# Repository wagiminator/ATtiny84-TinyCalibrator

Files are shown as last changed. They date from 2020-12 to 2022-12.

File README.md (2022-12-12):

# TinyCalibrator - OSC Calibrator and High-Voltage Fuse Resetter
Because the 8-pin ATtinys only have a few GPIO pins available, they are usually operated without an external clock. The internal oscillator does a good job in most applications, but when it comes to precise timing, its +/-10% accuracy is often insufficient. Fortunately, the oscillator can be calibrated, increasing its accuracy to +/-2% or better. There are a few ways to perform this manual calibration, but several steps are required. The TinyCalibrator does this fully automatically by a push of a button. In order to make the device more versatile, a high-voltage fuse resetter was also integrated, with which "bricked" ATtinys can be reset to the factory state. For an in-circuit oscillator calibrator take a look at [TinyICOC](https://github.com/wagiminator/ATtiny84-TinyICOC).

- Project Video (YouTube): https://youtu.be/PQvtNVte2JE
- Design Files (EasyEDA): https://easyeda.com/wagiminator/attiny84-tinycalibrator

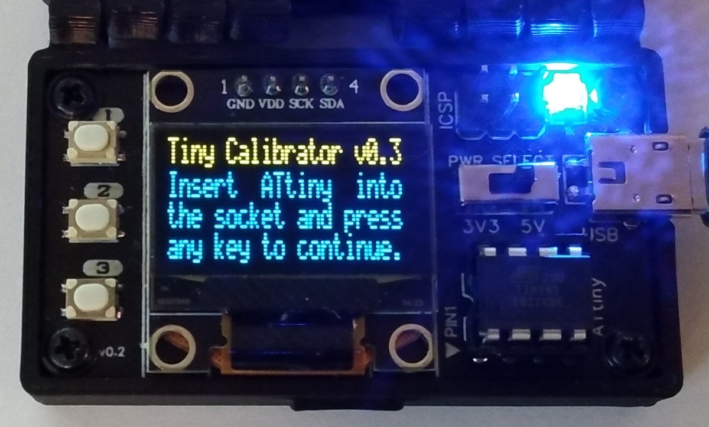
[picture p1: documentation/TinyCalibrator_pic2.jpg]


# Hardware
The TinyCalibrator is supplied with 5V via a [Micro USB connector](https://aliexpress.com/wholesale?SearchText=micro+usb+2pin+dip). Since the frequency of the oscillator depends on the supply voltage of the ATtiny, an [HT7333](https://datasheet.lcsc.com/szlcsc/Holtek-Semicon-HT7333-A_C21583.pdf) voltage regulator was integrated. A switch can then be used to choose whether the oscillator should be calibrated for 3.3V or 5V.

The [ATtiny84](http://ww1.microchip.com/downloads/en/devicedoc/Atmel-7701_Automotive-Microcontrollers-ATtiny24-44-84_Datasheet.pdf) was chosen as the microcontroller for the TinyCalibrator because it has exactly the necessary number of GPIO pins. For accurate frequency measurements, the ATtiny84 is operated with an external 12 MHz crystal. Since the current software version only requires about 3.7 KByte, an ATtiny44 can also be used.

To generate the 12V for the High-Voltage Serial Programmer, an [ST662A](https://datasheet.lcsc.com/szlcsc/2004081608_STMicroelectronics-ST662ACD-TR_C500661.pdf) charge pump IC was chosen, which was specially designed for such applications and needs only a few external components. The 12V is controlled by a MOSFET and applied to the RESET pin of the target ATtiny if necessary. The remaining programming lines to the target are protected against a short circuit with resistors.

The user interface utilizes three buttons and a [128x64 pixels OLED display](http://aliexpress.com/wholesale?SearchText=128+64+0.96+oled+new+4pin).

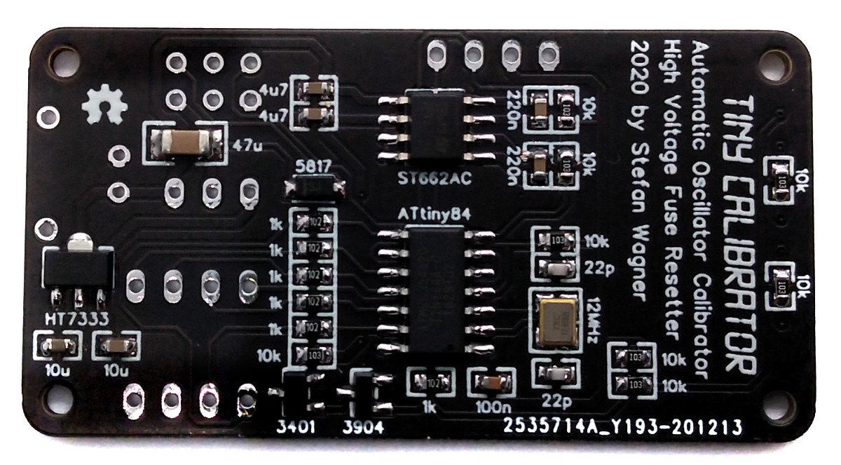
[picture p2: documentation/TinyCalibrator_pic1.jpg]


# Software
## Basic Principle
To carry out the calibration, a program is first uploaded to the target ATtiny using the integrated High-Voltage Serial Programmer. In addition, the factory oscillator calibration value (OSCCAL) is written to the EEPROM. The program on the target ATtiny reads the EEPROM and writes the value to the OSCCAL register. Then it applies an oscillating signal with half the clock frequency to pin PB0. Since the fuses were previously set so that the target ATtiny runs with a prescaler of 8, a signal with 1/16 of the oscillator frequency is applied to PB0.

```c
#include <avr/io.h>
#include <avr/eeprom.h>

int main(void) {
  OSCCAL = eeprom_read_byte(0);
  DDRB   = 0b00000001;
  TCCR0A = 0b01000010;
  TCCR0B = 0b00000001;
  while(1);
}
```

This frequency is measured by the TinyCalibrator and compared with the target value. The oscillator calibration value (OSCCAL) is then adjusted accordingly and written to the EEPROM of the target ATtiny. This process is repeated until the OSCCAL value, which leads to the lowest frequency deviation, has been found.

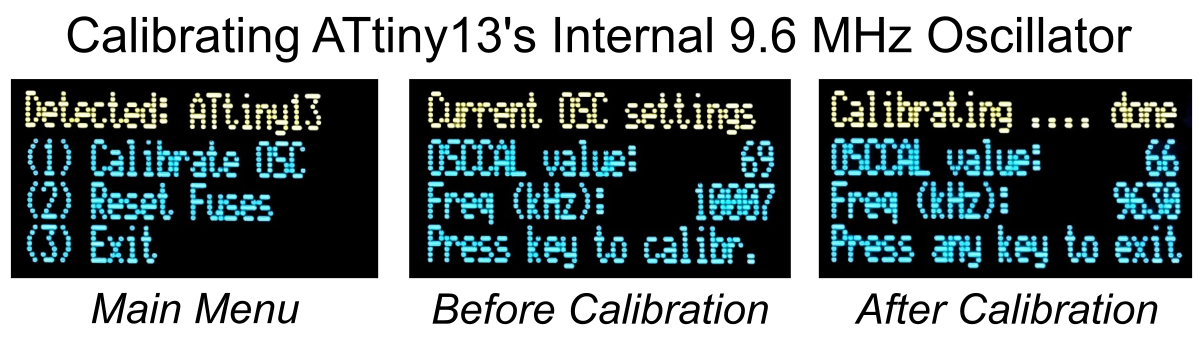
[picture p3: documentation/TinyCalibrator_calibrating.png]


## High-Voltage Serial Programmer
The code for the High-Voltage Serial Programmer (HVSP) is quite unspectacular. Simply put, for each action, a series of instructions are sent over the data lines to the target ATtiny and the corresponding response is read. The process and the instructions are well described in the data sheet.

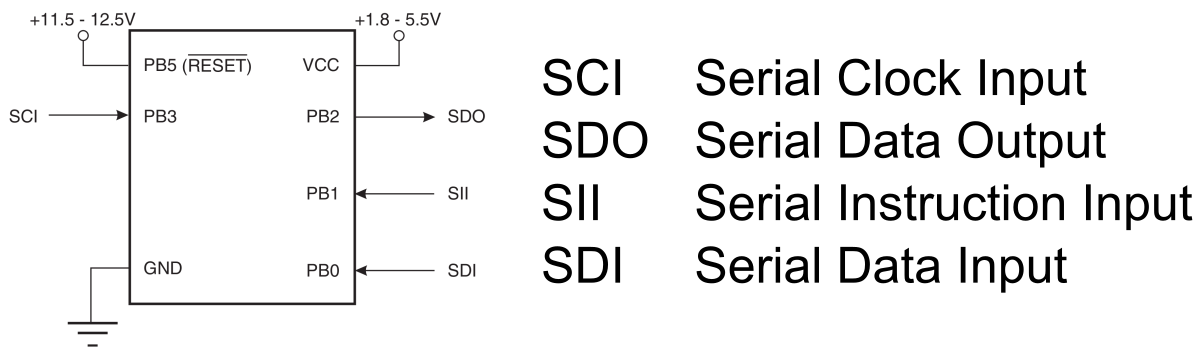
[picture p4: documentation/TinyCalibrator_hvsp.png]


## Frequency Measurement
The timer/counters of the ATtiny84 are used for the frequency measurement. PB0 of the target ATtiny, which outputs a signal with 1/16 of its oscillator frequency, is connected to the T0 input of the ATtiny84. Timer0 counts the pulses at T0 and timer1 stops the measurement after a time of 32 milliseconds. From this, the oscillator frequency of the target ATtiny can finally be calculated.

## I²C OLED Implementation
The I²C protocol implementation is based on a crude bitbanging method. It was specifically designed for the limited resources of ATtiny10 and ATtiny13, but it works with some other AVRs (including the ATtiny84) as well. The functions for the OLED are adapted to the SSD1306 OLED module, but they can easily be modified to be used for other modules. In order to save resources, only the basic functionalities which are needed for this application are implemented. For a detailed information on the working principle of the I²C OLED implementation visit [TinyOLEDdemo](https://github.com/wagiminator/attiny13-tinyoleddemo).

## Compiling and Uploading
### If using the Arduino IDE
- Make sure you have installed [ATtinyCore](https://github.com/SpenceKonde/ATTinyCore).
- Go to **Tools -> Board -> ATtinyCore** and select **ATtiny24/44/84(a) (No bootloader)**.
- Go to **Tools** and choose the following board options:
  - **Chip:**           ATtiny84(a)
  - **Clock:**          12 MHz (external)
  - **Millis/Micros:**  disabled
  - Leave the rest at the default settings
- Connect your programmer to your PC and to the ICSP header of the device.
- Go to **Tools -> Programmer** and select your ISP programmer (e.g. [USBasp](https://aliexpress.com/wholesale?SearchText=usbasp)).
- Go to **Tools -> Burn Bootloader** to burn the fuses.
- Open TinyCalibrator sketch and click **Upload**.

### If using the precompiled hex-file
- Make sure you have installed [avrdude](https://learn.adafruit.com/usbtinyisp/avrdude).
- Connect your programmer to your PC and to the ICSP header of the device.
- Open a terminal.
- Navigate to the folder with the hex-file.
- Execute the following command (if necessary replace "usbasp" with the programmer you use):
  ```
  avrdude -c usbasp -p t84 -U lfuse:w:0xff:m -U hfuse:w:0xd5:m -U efuse:w:0xff:m -U flash:w:tinycalibrator.hex
  ```

### If using the makefile (Linux/Mac)
- Make sure you have installed [avr-gcc toolchain and avrdude](http://maxembedded.com/2015/06/setting-up-avr-gcc-toolchain-on-linux-and-mac-os-x/).
- Connect your programmer to your PC and to the ICSP header of the device.
- Open a terminal.
- Navigate to the folder with the makefile and the Arduino sketch.
- Run `DEVICE=attiny84 PROGRMR=usbasp make install` to compile, burn the fuses and upload the firmware (change DEVICE and PROGRMR accordingly).

# Operating Instructions
1. Select the desired supply voltage (3.3V or 5V) with the switch.
2. Connect a 5V power supply to the micro USB port.
3. Place the ATtiny13/25/45/85 in the IC socket and press any key. Use an [SOP adapter](https://aliexpress.com/wholesale?SearchText=sop-8+150mil+200mil+adapter) for SMD parts.
4. Select the function you want and follow the instructions on the display.

After the calibration process, the optimal OSCCAL value remains in memory address 0 of the EEPROM and can continue to be used. To do this, program the EEFUSE to preserve EEPROM memory through the chip erase cycle, otherwise the OSCCAL value will be lost after uploading new firmware. Your code should then contain the following function:

```c
#include <avr/eeprom.h>
void readOSCCAL(void) {
  uint8_t value = eeprom_read_byte(0);
  if (value < 0xFF) OSCCAL = value;
}
```

Of course, the OSCCAL value can also be set directly without the EEPROM. Remember that the OSCCAL value is displayed in hexadecimal.

```c
OSCCAL = 0x66;
```

# References, Links and Notes
1. [TinyHVSP](https://github.com/wagiminator/ATtiny84-TinyHVSP)
2. [TinyICOC](https://github.com/wagiminator/ATtiny84-TinyICOC)
3. [I²C OLED Tutorial](https://github.com/wagiminator/attiny13-tinyoleddemo)
4. [Ralph Doncaster's PiggyFuse](https://nerdralph.blogspot.com/2018/05/piggyfuse-hvsp-avr-fuse-programmer.html)
5. [Oscillator Calibration Sketch for ATtiny13](https://github.com/MCUdude/MicroCore#internal-oscillator-calibration)
6. [Oscillator Calibration Sketch for ATtiny25/45/85](http://ernstc.dk/arduino/tinytuner.html)
7. [ATtiny84 Datasheet](http://ww1.microchip.com/downloads/en/devicedoc/Atmel-7701_Automotive-Microcontrollers-ATtiny24-44-84_Datasheet.pdf)
8. [ATtiny85 Datasheet](https://ww1.microchip.com/downloads/en/DeviceDoc/Atmel-2586-AVR-8-bit-Microcontroller-ATtiny25-ATtiny45-ATtiny85_Datasheet.pdf)
9. [ATtiny13A Datasheet](http://ww1.microchip.com/downloads/en/DeviceDoc/doc8126.pdf)

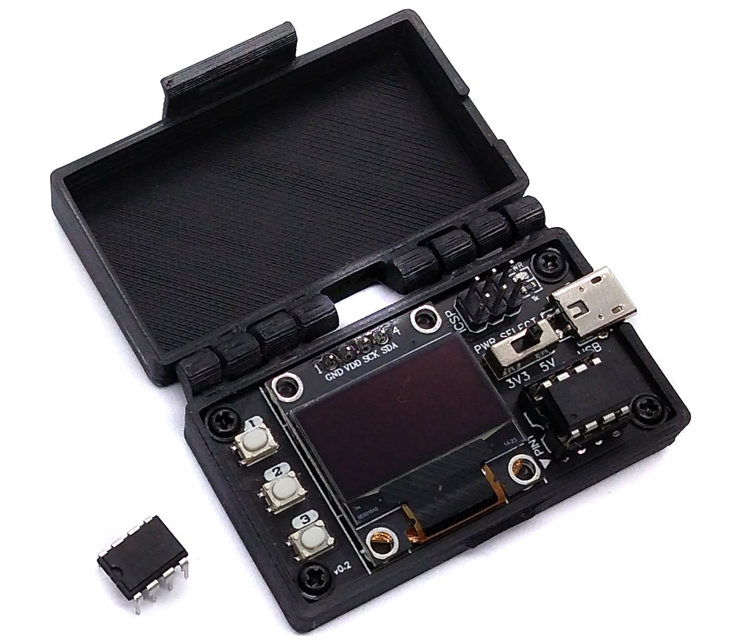
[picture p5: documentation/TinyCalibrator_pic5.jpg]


# License


This work is licensed under Creative Commons Attribution-ShareAlike 3.0 Unported License. 
(http://creativecommons.org/licenses/by-sa/3.0/)

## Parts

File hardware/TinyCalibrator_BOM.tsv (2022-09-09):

ID | Name | Designator | Footprint | Quantity | Manufacturer Part | Manufacturer | Supplier | Supplier Part | Price
1 | 100n | C1 | 603 | 1 | CC0603KRX7R9BB104 | YAGEO | LCSC | C14663 | 0.0041
2 | 47u | C2 | 1206 | 1 | 1206F476M160NT | FH | LCSC | C30300 | 0.3645
3 | 22p | C3,C4 | 603 | 2 | CL10C220JB8NNNC | SAMSUNG | LCSC | C1653 | 0.0054
4 | 220n | C5,C6 | 603 | 2 | CL10B224KA8NNNC | SAMSUNG | LCSC | C21120 | 0.0069
5 | 4u7 | C7,C8 | 603 | 2 | CL10A475KA8NQNC | SAMSUNG | LCSC | C69335 | 0.0273
6 | 10u | C9,C10 | 603 | 2 | CL10A106MA8NRNC | SAMSUNG | LCSC | C96446 | 0.0359
7 | 5817 | D1 | SCHOTTKY-SOD-123 | 1 | 1N5817W |  | LCSC | C727113 | 0.0286
8 | ICSP | H1 | ICSP-6-B | 1 | C65114 | BOOMELE | LCSC | C65114 | 0.0342
9 | OLED | H2 | I2C OLED 0.96 NEW | 1 | SSD1306 I2C OLED
10 | PWR | LED1 | LED_0603 | 1 | 19-217/BHC-ZL1M2RY/3T | EVERLIGHT | LCSC | C72041 | 0.0182
11 | AO3401A | Q1 | SOT-23-3 | 1 | AO3401A | AOS | LCSC | C15127 | 0.1864
12 | MMBT3904 | Q2 | SOT-23-3 | 1 | MMBT3904 | CJ | LCSC | C20526 | 0.0177
13 | 1k | R2,R5,R7,R8,R9,R10,R15 | 603 | 7 | 0603WAF1001T5E | UniOhm | LCSC | C21190 | 0.0013
14 | 10k | R1,R3,R4,R6,R11,R12,R13,R14 | 603 | 8 | 0603WAF1002T5E | UniOhm | LCSC | C25804 | 0.0014
15 | TS-1089S-02526 | SW1,SW2,SW3 | SW-SMD_4P-L4.2-W3.3 | 3 | TS-1089S-02526 | XUNPU | LCSC | C455282 | 0.0534
16 | PWRSLCT | SW4 | SLIDE SWITCH DPDT 1P2T | 1 | SS-12D01-G2 | USAKRO | LCSC | C698215 | 0.0454
17 | ATTINY84A-SSU | U1 | SOIC-14_150MIL | 1 | ATTINY84A-SSU | MICROCHIP | LCSC | C144333 | 2.0002
18 | ST662ACD-TR | U2 | SOP-8_150MIL | 1 | ST662ACD-TR | STMicroelectronics | LCSC | C500661 | 0.8368
19 | HT7333-A | U3 | SOT-89-3_L4.5-W2.5-P1.50-LS4.2-BR | 1 | HT7333-A | HOLTEK | LCSC | C21583 | 0.2939
20 | DIP8 SOCKET | U4 | DIP8 PACKAGE | 1 | DS1009-08AT1NX-0A2 | CONNFLY | LCSC | C72124 | 0.0336
21 | USB PWR Connector | USB1 | USB PWR CONNECTOR | 1 | KH-MICRO-SMT.J-2P | Shenzhen Kinghelm Elec | LCSC | C2688799 | 0.0549
22 | 12MHz | X1 | OSC-SMD_3225 | 1 | X322512MSB4SI | YXC | LCSC | C9002 | 0.1064

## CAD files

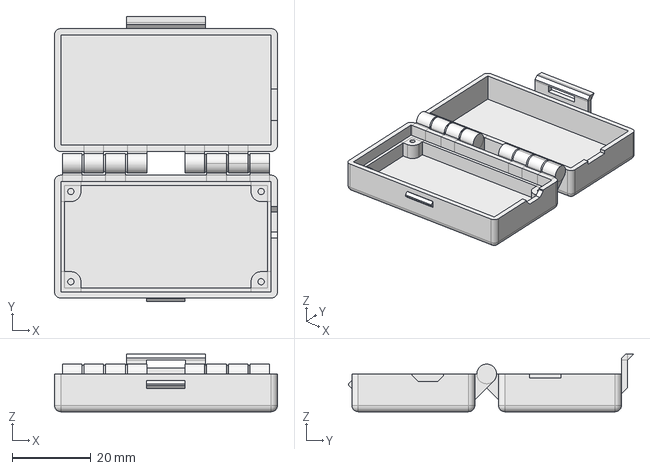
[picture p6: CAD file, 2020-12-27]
3dprint/TinyCalibrator_case.fcstd
56.6 x 72.4 x 14.6 mm

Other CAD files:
3dprint/TinyCalibrator_case.stl

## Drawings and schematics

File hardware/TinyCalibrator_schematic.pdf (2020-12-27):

## ATtiny84 Microcontroller

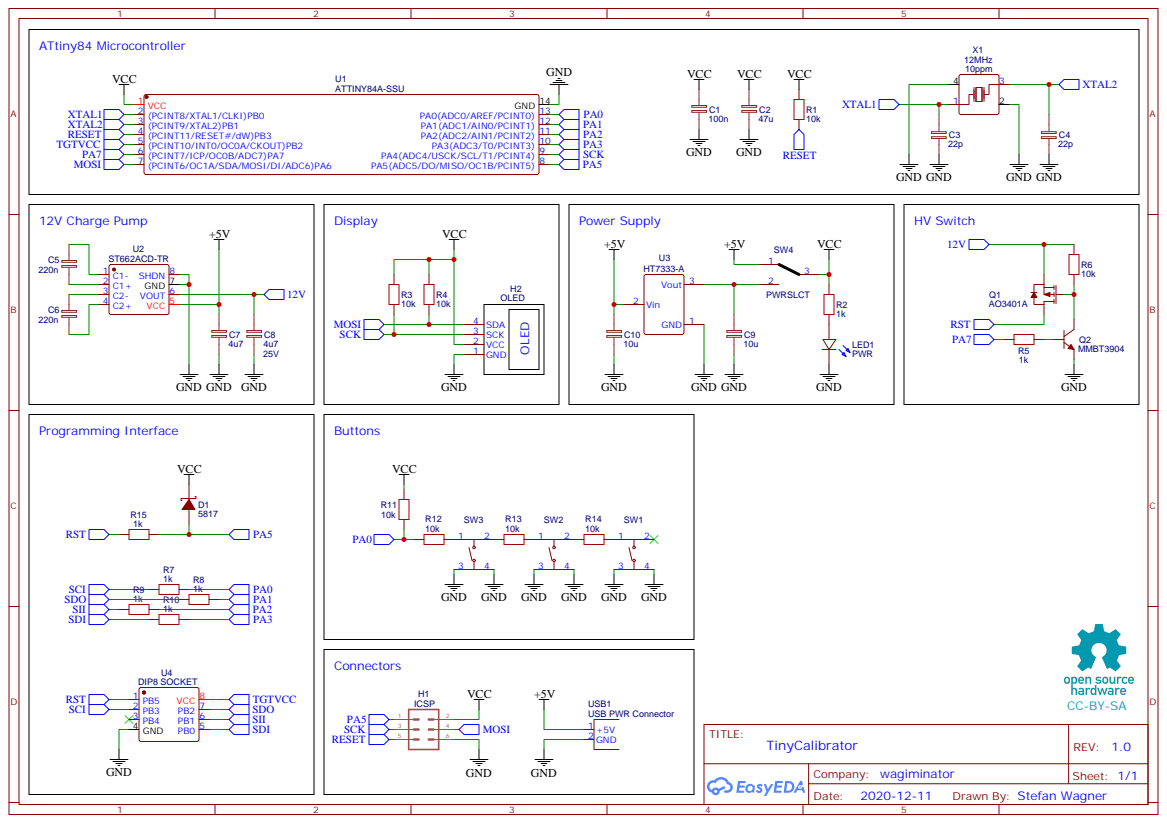
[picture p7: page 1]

GND GND GND

Drawn By: Stefan Wagner

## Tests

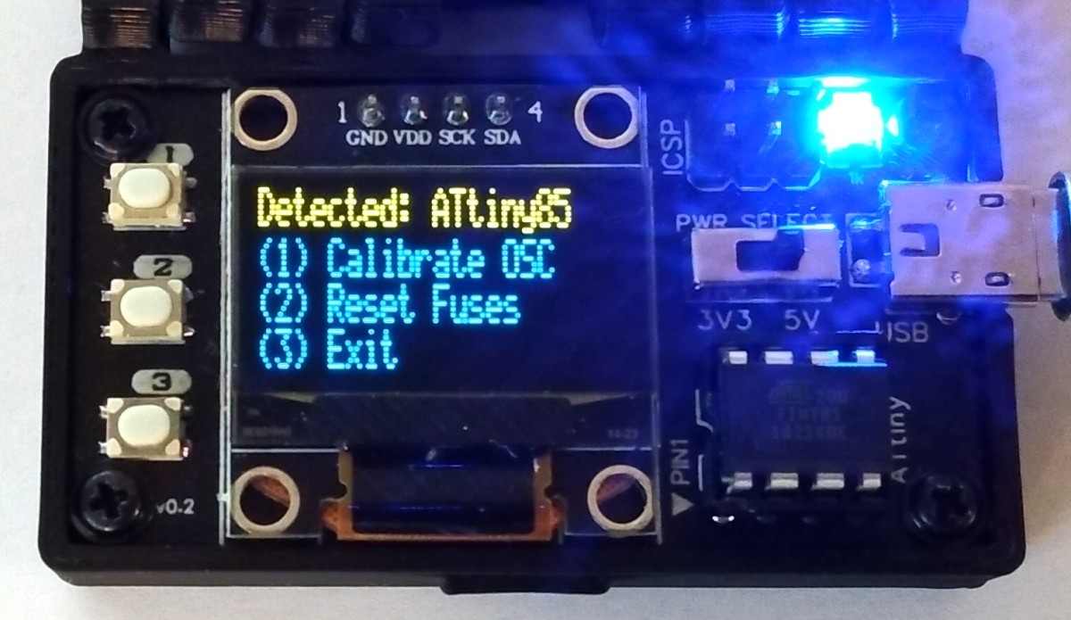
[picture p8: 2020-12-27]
documentation/TinyCalibrator_pic3.jpg

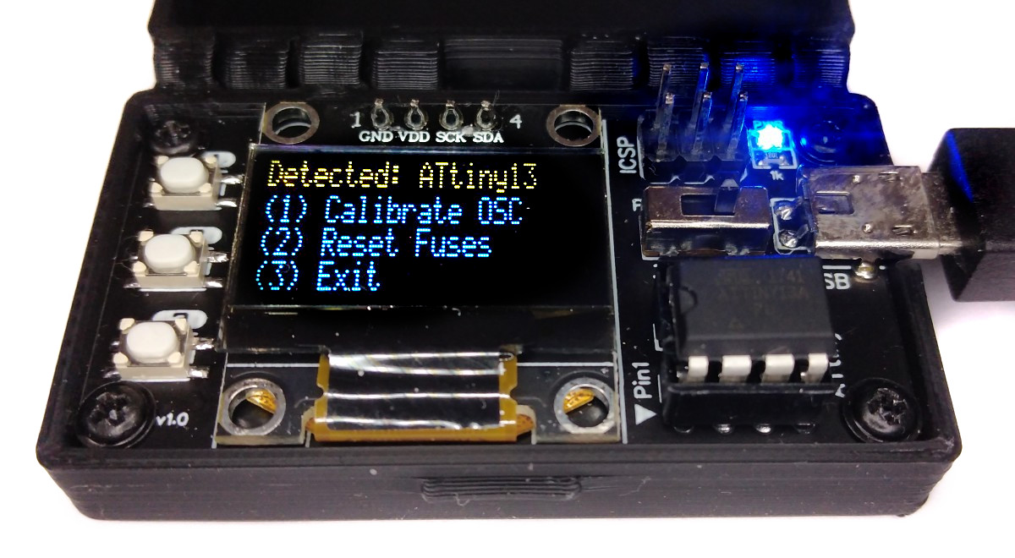
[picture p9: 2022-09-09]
documentation/TinyCalibrator_pic6.jpg

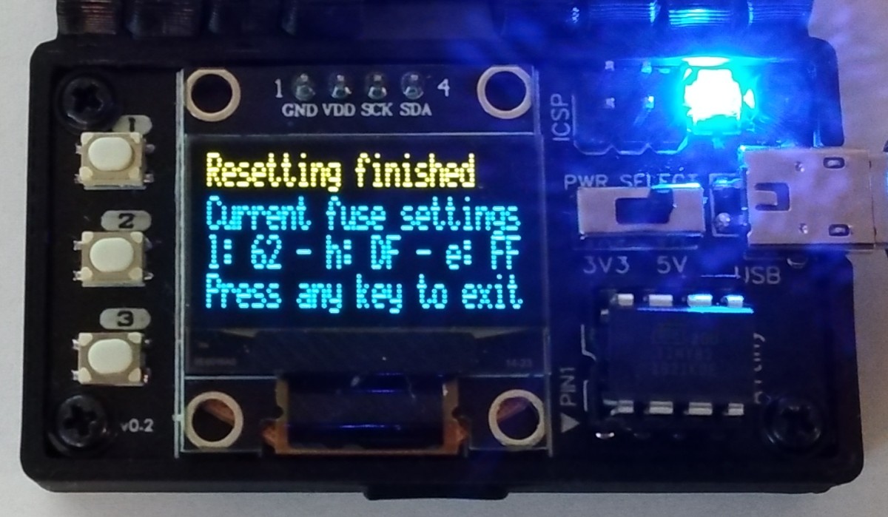
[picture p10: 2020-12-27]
documentation/TinyCalibrator_pic4.jpg

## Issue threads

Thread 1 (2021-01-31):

update signature row with tuned OSCCAL value

nerdralph, 2021-01-31:
A few years ago I started working on a HV OSCCAL tuner that uses undocumented commands to modify the signature row calibration values.  I got a prototype version working, and then started work to discover how to do it without HV.  I was able to erase the signature page, but a couple attempts to brute force search for the write signature page command did not succeed.

I never got around to cleaning up the code, but after seeing your project I thought it would be a useful feature in HV mode to skip the use of EEPROM and just modify the OSCCAL value that gets loaded on reset.  Here's the code:
https://github.com/nerdralph/piggy-prog/tree/master/PiggyTune

wagiminator, 2021-01-31:
That would of course be fantastic. I was annoyed that the calibration bytes cannot be written to. When I find a little more time again, I try to understand your code and implement it for the calibrator.

nerdralph, 2021-02-04:
I can't see anything obvious.  I'll have to set up my HV programmer to
re-test the code.  I had a t13 that had its signature page accidentally
erased, and I was able to restore it, so I'm confident that part works.  It
looks like I didn't test the erase sig before I set the project aside for
other priorites.
There's some old AVRfreaks discussions about the undocumented commands.
I'll check my bookmarks and add them to the code comments.

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

nerdralph, 2021-02-04:
Here's one of the avrfreaks discussions about the signature commands.
https://www.avrfreaks.net/comment/165751#comment-165751

wagiminator, 2021-02-04:
These are exactly the same instructions. I would agree with you that the first problem is with erasing the signature page. Since that does not work, writing to the page cannot work either.

nerdralph, 2021-02-04:
I recall testing the AC C0 00 00 command to erase the signature page which is mentioned here:
https://www.avrfreaks.net/forum/undocumented-signature-row-contents?name=PNphpBB2&file=viewtopic&t=140556

It's been a while since I was working on this.  The couple of files I found have dates from the summer of 2018.  I'm certain I was able to erase and then re-program the signature page, but it's possible I was using the ICSP (low-voltage) command to erase the page, and then using the HV command to re-write the page.

I still plan to re-assemble my HV programming circuit, though I'm not sure how much more work I'll do on the OSCCAL tuning.  As you probably have noticed, it's primarily the t13 that needs OSCCAL tuning.  All my t85's have been within 1-2% of spec.  And for people that want a simple way to tune the speed, I wrote picoboot-lib, which is an Arduino compatible serial bootloader with automatic OSCCAL tuning.

wagiminator, 2021-02-05:
This is obviously an ICSP command. I will test it, but it will take a while, because I have to deal with the ICSP protocol first.
In fact, the ATtiny13 in particular needs OSCCAL tuning, but as you may have noticed, I like to use it a lot ;-)

wagiminator, 2021-02-05:
So, I quickly implemented the ICSP protocol (it's even easier than HVSP), but unfortunately I still can't erase the signature page ;-(

nerdralph, 2021-02-05:
>
>
> So, I quickly implemented the ICSP protocol (it's even easier than HVSP), but unfortunately I still can't erase the signature page ;-(

That's interesting.  I didn't have these problems, and I had found at least 2 other people on avrfreaks that had tested the undocumented commands.  That leads me to two explanations:
1)  Atmel/Microchip changed the method of factory programming the signature row.
2) You have a clone MCU which implements the documented functionality, but not the undocumented functionality.

Have you ever used debugWire on these t13s?  Although it is documented in the datasheet that debugWire is supported, the actual protocol was never documented by Atmel.  This would make it difficult for a clone to properly implement debugWire.
dwprog is my preferred debugWire tool:
https://github.com/nerdralph/dwprog

wagiminator, 2021-02-05:
Aha, the second point might apply. I bought 50 ATtiny13A for € 10 on aliexpress. I'll try that with a few other chips (hopefully my ATtiny85 are original). However, if that is the problem, then either it makes no sense to implement this feature in the calibrator, or I would have to run a test before calibrating.

nerdralph, 2021-02-05:
I agree.  The mere presence of clones that don't work diminishes the value of the technique.  And at the same time, it probably increases the need for tuning as a clone manufacturer is less likely to tune and program each die.

wagiminator, 2021-02-08:
I have now tried it with several ATtiny13/25/85 in DIP and SMD packages, unfortunately still without success. But as far as I can remember, I bought all of them on Aliexpress, so that doesn't mean a lot. Of course, there is also the possibility that I have a mistake somewhere.

nerdralph, 2021-02-08:
I started playing with HV programming again yesterday.  Partially killed one of my t13s.  I have an updated circuit with a PNP+NPN (similar to your pFET + NPN setup).  Over the next few days I hope to at least have a schematic + code that works, so you can try to duplicate it.

The fact that you've tried multiple different parts leads me to believe there's something different in your setup than mine.  I wouldn't rule out one batch of your AVRs being clones, but it seems unlikely all of them are.  I think about half of my 8-pin AVRs were purchased from Asia.

It may be a red herring, but I had found the HVSP wasn't as simple as following the datasheet instructions, and the t13s I tested had significantly different timing than the t85s.
http://nerdralph.blogspot.com/2018/05/piggyfuse-hvsp-avr-fuse-programmer.html

nerdralph, 2021-02-09:
I'm not able to get the "0xAC 0xC0 0 0" to erase the signature page either.  I tried 2 t13s (SOIC & DIP), a t85, and a DIP t88 that I bought from Newark/Element14.  However I know there is a way to erase the signature page because I built the HV programmer and re-wrote the signature page after I accidentally erased the signature page during regular programming when I forgot to connect VCC and ended up powering the target AVR through the protection diodes on the SCK and MOSI lines.  The signature and calibration all read as 0xFF, and with the HV command I was able to restore the signature and OSCCAL.

Back in the summer of 2018, I wrote a program to try to find the LV serial programming command to write the calibration page by partial brute force.  I was guessing what the first command byte would likely be, and the program runs through all 16.8 million possibilities for the next 3 bytes.

I think I'll move on to testing the HV commands.  Once I get that working again I'll document my exact hardware & firmware setup so you can try to duplicate it.

wagiminator, 2021-02-09:
Then I wish you maximum success! It remains exciting.

nerdralph, 2021-02-10:
I did a bunch of testing this eve, and got it to work on the 2nd t13 DIP I tried:
```
HSVP fuse resetter
1E 5C 90 5C 7 FF FF FF FF FF FF FF FF FF 57 34 33 30 37 30 FF 9 4C 38 17 4 12 22 13 22 EE 9
Signature: 9007
OSCCAL: 5C
Found 0x5C OSCCAL, trying erase
LFuse: 76, HFuse: FF, EFuse: FF, Lock: FF
68 us lock bit read time.
Detected t13.
Debug fuses programmed.
8856 us.
Signature: FFFF
LFuse: 76, HFuse: FF, EFuse: FF, Lock: FF
Done. Reset programmer to run again.
▒▒▒▒
HSVP fuse resetter
FF FF FF FF FF FF FF FF FF FF FF FF FF FF FF FF FF FF FF FF FF FF FF FF FF FF FF FF FF FF FF FF
Signature: FFFF
OSCCAL: FF
LFuse: 76, HFuse: FF, EFuse: FF, Lock: FF
68 us lock bit read time.
Blank signature. resetting to t13 0x5E OSCCAL
missing signature.
No fuses programmed.
24444 us.
Signature: 9007
LFuse: 76, HFuse: FF, EFuse: FF, Lock: FF
Done. Reset programmer to run again.
```
I don't recall where I bought them, or even if I bought both of them from the same supplier.  The extended signature bytes were quite similar on both.

wagiminator, 2021-02-10:
Congratulations! So it works, but not with every chip? Did you use a t13 or a t13a?

nerdralph, 2021-02-10:
>
>
> Congratulations! So it works, but not with every chip? Did you use a t13 or a t13a?

Both t13a, and both with the same date code of 1430, so I likely bought them together from the same supplier.  The underside of the DIP package has TAIWAN in the circle, so that's probably where they are made.

If I'm feeling more adventurous, I may hook up the scope and compare the the two parts.

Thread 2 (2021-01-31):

3V3 in HV mode?

nerdralph, 2021-01-31:
Does HV work with the target Vcc at 3V3?  For HV programming mode, the datasheet says: "Apply 4.5 - 5.5V between V CC and GND".

wagiminator, 2021-01-31:
I know, but it still works with no problems.

nerdralph, 2021-01-31:
OK, I hadn't tested it myself, but I'm not surprised it works outside the datasheet specs.

wagiminator, 2021-01-31:
One picture in the data sheet shows 1.8V-5.5V, so I just tried it out before implementing extra low-voltage serial programming routines.

Closed 2021-01-31.

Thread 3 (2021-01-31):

cost reduction/optimization options

nerdralph, 2021-01-31:
The t84 RC oscillator is much better than the t85 when it comes to stability and tuning resolution.  Last year I wrote an improved OSCCAL tuning function for Micronucleus, that could be used in your calibrator project.
https://github.com/nerdralph/micronucleus-firmware/blob/asm/firmware/osccal.S
This issue thread has some details about the tuning:
https://github.com/micronucleus/micronucleus/issues/182

This would also free up 2 pins on the t84, and one or both of them could be then used for a PWM-based charge pump instead of the external ST662.

nerdralph, 2021-01-31:
I mistakenly thought there was a USB connector on the back of the PCB, and the firmware was using V-USB.  Since it's not, that makes the USB tuning suggestion pointless.
I still think you can drop the external xtal though, by calibrating the t84's RC oscillator, if necessary.  Since the t84 RC oscillator is more stable and has finer tuning resolution than the t13 and tx5, the tuning accuracy would not suffer by a material amount.

wagiminator, 2021-01-31:
I'm sure you're right, the crystal is a little overkill for this purpose. With the two pins you can do great things, for example realizing the 12V charge pump with the ATtiny and thus saving the ST662 or saving yourself this stupid pin sharing of the buttons and SCI line, which has caused me a lot of headaches (this was a really bad decision). Anyway, despite the many opportunities for improvement, the hardware does its job, so that a change is not on my priority list for the time being. The thing with the signature row is more important, I think.

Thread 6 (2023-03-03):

Not realy an issue, except for me ...

laverdanny, 2023-03-03:
Hi
Great work !

I'm dealing with some ATTiny85, and I already "bricked" some don't really know how

I'd like to get one of your Calibrator, in order to reset them, and I'll appreciate to get more precise timings too !

Unhopefully for me, I don't have skills to make it, I'm prettty sure I don't have necessary tools, and several components aren't sold on unitary basis, so I'd like to get a ready-to-work one. Is there a way ?

Regards

wagiminator, 2023-03-12:
Hi, sorry, not to buy, only to DIY.

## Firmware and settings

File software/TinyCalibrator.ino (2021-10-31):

// ===================================================================================
// Project:   TinyCalibrator - OSC Calibrator and High-Voltage Fuse Resetter
// Version:   v1.0
// Year:      2020
// Author:    Stefan Wagner
// Github:    https://github.com/wagiminator
// EasyEDA:   https://easyeda.com/wagiminator
// License:   http://creativecommons.org/licenses/by-sa/3.0/
// ===================================================================================
//
// Description:
// ------------
// Because the ATtinys only have a few pins available, they are usually
// operated without an external clock. The internal oscillator does a good
// job in most applications, but when it comes to precise timing, it is
// too inaccurate. The accuracy of the oscillator of an ATtiny is only 
// +/-10%. Fortunately, the oscillator can be calibrated, increasing its
// accuracy to +/-2% or better. There are a few ways to perform this manual
// calibration, but several steps are required. The TinyCalibrator does
// this fully automatically by a push of a button. In order to make the
// device more versatile, a high-voltage fuse resetter was also integrated,
// with which "bricked" ATtinys can be reset to the factory state.
//
// To carry out the calibration, a program is first uploaded to the target
// ATtiny using the integrated high-voltage serial programmer. This program
// applies an oscillating signal with half the clock frequency to pin PB0
// of the target ATtiny. Since the fuses were previously set so that the
// target ATtiny runs with a prescaler of 8, a signal with 1/16 of the
// oscillator frequency is applied to its PB0. This frequency is measured
// by the timers of the ATtiny84 and compared with the target value.
// The oscillator calibration value (OSCCAL) is then adjusted accordingly
// and written into the EEPROM of the target ATtiny. This value is in turn
// read by the target ATtiny and written to its OSCCAL register. This process
// is repeated until the OSCCAL value, which leads to the lowest frequency
// deviation, has been found.
//
// References:
// -----------
// The high-voltage serial programmer implementation is based on TinyHVSP
// https://github.com/wagiminator/ATtiny84-TinyHVSP
//
// The I²C OLED implementation is based on TinyOLEDdemo
// https://github.com/wagiminator/ATtiny13-TinyOLEDdemo
//
// The OLED font was adapted from Neven Boyanov and Stephen Denne
// https://github.com/datacute/Tiny4kOLED
//
// A big thank you to Ralph Doncaster (nerdralph) for his optimization tips.
// https://nerdralph.blogspot.com/ , https://github.com/nerdralph
//
// Wiring:
// -------
//                                  +-\/-+
//                            Vcc  1|°   |14  GND
//  12M CRYSTAL -------- XTAL PB0  2|    |13  PA0 ADC0 AREF --- TGT SCI + Buttons
//  12M CRYSTAL -------- XTAL PB1  3|    |12  PA1 ADC1 AIN0 --- TGT SDO
//        RESET -------- !RST PB3  4|    |11  PA2 ADC2 AIN1 --- TGT SII
//      TGT Vcc -------- INT0 PB2  5|    |10  PA3 ADC3 T0 ----- TGT SDI
//  TGT RST 12V -------- ADC7 PA7  6|    |9   PA4 ADC4 SCK ---- I2C SCK OLED
// I2C SDA OLED --- MOSI ADC6 PA6  7|    |8   PA5 ADC5 MISO --- TGT RST 0V
//                                  +----+
//
// Compilation Settings:
// ---------------------
// Core:      ATtinyCore (https://github.com/SpenceKonde/ATTinyCore)
// Board:     ATtiny24/44/84(a) (No bootloader)
// Chip:      ATtiny44(a) or ATtiny84(a)
// Clock:     12 MHz (external)
// Millis:    disabled
// BOD:       2.7V
//
// Leave the rest on default settings. Don't forget to "Burn bootloader"!
// No Arduino core functions or libraries are used. Use the makefile if 
// you want to compile without Arduino IDE.
//
// Fuse settings: -U lfuse:w:0xff:m -U hfuse:w:0xd5:m -U efuse:w:0xff:m


// ===================================================================================
// Libraries and Definitions
// ===================================================================================

// Libraries
#include <avr/io.h>         // for GPIO
#include <avr/interrupt.h>  // for interrupts
#include <avr/pgmspace.h>   // to store data in programm memory
#include <util/delay.h>     // for delays

// Pin definitions PORTA
#define I2C_SCL   PA4       // I2C Serial Clock (SCK)
#define I2C_SDA   PA6       // I2C Serial Data (SDA)
#define SCI_PIN   PA0       // Serial Clock Input (SCI)       Pin 2 of target device
#define SDO_PIN   PA1       // Serial Data Output (SDO)       Pin 7 of target device
#define SII_PIN   PA2       // Serial Instruction Input (SII) Pin 6 of target device
#define SDI_PIN   PA3       // Serial Data Input (SDI)        Pin 5 of target device
#define RST_PIN   PA5       // Low  Voltage RESET             Pin 1 of target device
#define HVR_PIN   PA7       // High Voltage RESET             Pin 1 of target device
#define BUTTONS   PA0       // Buttons

// Pin definitions PORTB
#define VCC_PIN   PB2       // Target VCC                     Pin 8 of target device

// Global variables
uint8_t  inLFUSE, inHFUSE, inEFUSE;           // for reading fuses
uint8_t  outLFUSE, outHFUSE, outEFUSE;        // for writing fuses
uint8_t  inCALIB0, inCALIB1;                  // for reading calibration bytes
uint8_t  inLOCK;                              // for reading lock bits
uint8_t  target;                              // for target device
uint16_t signature;                           // for reading signature
uint16_t frequency;                           // for measures frequency in kHz

// ===================================================================================
// I2C Implementation
// ===================================================================================

// I2C macros
#define I2C_SDA_HIGH()  DDRA &= ~(1<<I2C_SDA) // release SDA   -> pulled HIGH by resistor
#define I2C_SDA_LOW()   DDRA |=  (1<<I2C_SDA) // SDA as output -> pulled LOW  by MCU
#define I2C_SCL_HIGH()  DDRA &= ~(1<<I2C_SCL) // release SCL   -> pulled HIGH by resistor
#define I2C_SCL_LOW()   DDRA |=  (1<<I2C_SCL) // SCL as output -> pulled LOW  by MCU
#define I2C_DELAY()     asm("lpm")            // delay 3 clock cycles
#define I2C_CLOCKOUT()  I2C_SCL_HIGH(); I2C_DELAY(); I2C_SCL_LOW()  // clock out

// I2C init function
void I2C_init(void) {
  DDRA  &= ~((1<<I2C_SDA)|(1<<I2C_SCL));  // pins as input (HIGH-Z) -> lines released
  PORTA &= ~((1<<I2C_SDA)|(1<<I2C_SCL));  // should be LOW when as ouput
}

// I2C transmit one data byte to the slave, ignore ACK bit, no clock stretching allowed
void I2C_write(uint8_t data) {
  for(uint8_t i = 8; i; i--, data<<=1) {  // transmit 8 bits, MSB first
    (data & 0x80) ? (I2C_SDA_HIGH()) : (I2C_SDA_LOW());  // SDA HIGH if bit is 1
    I2C_CLOCKOUT();                       // clock out -> slave reads the bit
  }
  I2C_DELAY();                            // delay 3 clock cycles
  I2C_SDA_HIGH();                         // release SDA for ACK bit of slave
  I2C_CLOCKOUT();                         // 9th clock pulse is for the ignored ACK bit
}

// I2C start transmission
void I2C_start(uint8_t addr) {
  I2C_SDA_LOW();                          // start condition: SDA goes LOW first
  I2C_SCL_LOW();                          // start condition: SCL goes LOW second
  I2C_write(addr);                        // send slave address
}

// I2C stop transmission
void I2C_stop(void) {
  I2C_SDA_LOW();                          // prepare SDA for LOW to HIGH transition
  I2C_SCL_HIGH();                         // stop condition: SCL goes HIGH first
  I2C_SDA_HIGH();                         // stop condition: SDA goes HIGH second
}

// ===================================================================================
// OLED Implementation
// ===================================================================================

// OLED definitions
#define OLED_ADDR       0x78              // OLED write address
#define OLED_CMD_MODE   0x00              // set command mode
#define OLED_DAT_MODE   0x40              // set data mode
#define OLED_INIT_LEN   9                 // length of init command array

// OLED init settings
const uint8_t OLED_INIT_CMD[] PROGMEM = {
  0xC8, 0xA1,   // flip screen
  0xA8, 0x1F,   // set multiplex ratio
  0xDA, 0x02,   // set com pins hardware configuration
  0x8D, 0x14,   // set DC-DC enable
  0xAF          // display on
};

// OLED 5x8 pixels character set
const uint8_t OLED_FONT[] PROGMEM = {
  0x00, 0x00, 0x00, 0x00, 0x00, 0x00, 0x00, 0x2F, 0x00, 0x00, 0x00, 0x07, 0x00, 0x07, 0x00,
  0x14, 0x7F, 0x14, 0x7F, 0x14, 0x24, 0x2A, 0x7F, 0x2A, 0x12, 0x23, 0x13, 0x08, 0x64, 0x62,
  0x36, 0x49, 0x55, 0x22, 0x50, 0x00, 0x05, 0x03, 0x00, 0x00, 0x00, 0x1C, 0x22, 0x41, 0x00,
  0x00, 0x41, 0x22, 0x1C, 0x00, 0x14, 0x08, 0x3E, 0x08, 0x14, 0x08, 0x08, 0x3E, 0x08, 0x08,
  0x00, 0x00, 0xA0, 0x60, 0x00, 0x08, 0x08, 0x08, 0x08, 0x08, 0x00, 0x60, 0x60, 0x00, 0x00,
  0x20, 0x10, 0x08, 0x04, 0x02, 0x3E, 0x51, 0x49, 0x45, 0x3E, 0x00, 0x42, 0x7F, 0x40, 0x00,
  0x42, 0x61, 0x51, 0x49, 0x46, 0x21, 0x41, 0x45, 0x4B, 0x31, 0x18, 0x14, 0x12, 0x7F, 0x10,
  0x27, 0x45, 0x45, 0x45, 0x39, 0x3C, 0x4A, 0x49, 0x49, 0x30, 0x01, 0x71, 0x09, 0x05, 0x03,
  0x36, 0x49, 0x49, 0x49, 0x36, 0x06, 0x49, 0x49, 0x29, 0x1E, 0x00, 0x36, 0x36, 0x00, 0x00,
  0x00, 0x56, 0x36, 0x00, 0x00, 0x08, 0x14, 0x22, 0x41, 0x00, 0x14, 0x14, 0x14, 0x14, 0x14,
  0x00, 0x41, 0x22, 0x14, 0x08, 0x02, 0x01, 0x51, 0x09, 0x06, 0x32, 0x49, 0x59, 0x51, 0x3E,
  0x7C, 0x12, 0x11, 0x12, 0x7C, 0x7F, 0x49, 0x49, 0x49, 0x36, 0x3E, 0x41, 0x41, 0x41, 0x22,
  0x7F, 0x41, 0x41, 0x22, 0x1C, 0x7F, 0x49, 0x49, 0x49, 0x41, 0x7F, 0x09, 0x09, 0x09, 0x01,
  0x3E, 0x41, 0x49, 0x49, 0x7A, 0x7F, 0x08, 0x08, 0x08, 0x7F, 0x00, 0x41, 0x7F, 0x41, 0x00,
  0x20, 0x40, 0x41, 0x3F, 0x01, 0x7F, 0x08, 0x14, 0x22, 0x41, 0x7F, 0x40, 0x40, 0x40, 0x40,
  0x7F, 0x02, 0x0C, 0x02, 0x7F, 0x7F, 0x04, 0x08, 0x10, 0x7F, 0x3E, 0x41, 0x41, 0x41, 0x3E,
  0x7F, 0x09, 0x09, 0x09, 0x06, 0x3E, 0x41, 0x51, 0x21, 0x5E, 0x7F, 0x09, 0x19, 0x29, 0x46,
  0x46, 0x49, 0x49, 0x49, 0x31, 0x01, 0x01, 0x7F, 0x01, 0x01, 0x3F, 0x40, 0x40, 0x40, 0x3F,
  0x1F, 0x20, 0x40, 0x20, 0x1F, 0x3F, 0x40, 0x38, 0x40, 0x3F, 0x63, 0x14, 0x08, 0x14, 0x63,
  0x07, 0x08, 0x70, 0x08, 0x07, 0x61, 0x51, 0x49, 0x45, 0x43, 0x00, 0x7F, 0x41, 0x41, 0x00,
  0x02, 0x04, 0x08, 0x10, 0x20, 0x00, 0x41, 0x41, 0x7F, 0x00, 0x04, 0x02, 0x01, 0x02, 0x04,
  0x40, 0x40, 0x40, 0x40, 0x40, 0x00, 0x01, 0x02, 0x04, 0x00, 0x20, 0x54, 0x54, 0x54, 0x78,
  0x7F, 0x48, 0x44, 0x44, 0x38, 0x38, 0x44, 0x44, 0x44, 0x20, 0x38, 0x44, 0x44, 0x48, 0x7F,
  0x38, 0x54, 0x54, 0x54, 0x18, 0x08, 0x7E, 0x09, 0x01, 0x02, 0x18, 0xA4, 0xA4, 0xA4, 0x7C,
  0x7F, 0x08, 0x04, 0x04, 0x78, 0x00, 0x44, 0x7D, 0x40, 0x00, 0x40, 0x80, 0x84, 0x7D, 0x00,
  0x7F, 0x10, 0x28, 0x44, 0x00, 0x00, 0x41, 0x7F, 0x40, 0x00, 0x7C, 0x04, 0x18, 0x04, 0x78,
  0x7C, 0x08, 0x04, 0x04, 0x78, 0x38, 0x44, 0x44, 0x44, 0x38, 0xFC, 0x24, 0x24, 0x24, 0x18,
  0x18, 0x24, 0x24, 0x18, 0xFC, 0x7C, 0x08, 0x04, 0x04, 0x08, 0x48, 0x54, 0x54, 0x54, 0x20,
  0x04, 0x3F, 0x44, 0x40, 0x20, 0x3C, 0x40, 0x40, 0x20, 0x7C, 0x1C, 0x20, 0x40, 0x20, 0x1C,
  0x3C, 0x40, 0x30, 0x40, 0x3C, 0x44, 0x28, 0x10, 0x28, 0x44, 0x1C, 0xA0, 0xA0, 0xA0, 0x7C,
  0x44, 0x64, 0x54, 0x4C, 0x44, 0x08, 0x36, 0x41, 0x41, 0x00, 0x00, 0x00, 0x7F, 0x00, 0x00,
  0x00, 0x41, 0x41, 0x36, 0x08, 0x08, 0x04, 0x08, 0x10, 0x08, 0xFF, 0xFF, 0xFF, 0xFF, 0xFF
};

// OLED variables
uint8_t OLED_x, OLED_y;                   // current cursor position

// OLED init function
void OLED_init(void) {
  I2C_init();                             // initialize I2C first
  I2C_start(OLED_ADDR);                   // start transmission to OLED
  I2C_write(OLED_CMD_MODE);               // set command mode
  for(uint8_t i = 0; i < OLED_INIT_LEN; i++)
    I2C_write(pgm_read_byte(&OLED_INIT_CMD[i])); // send the command bytes
  I2C_stop();                             // stop transmission
}

// OLED set the cursor
void OLED_setCursor(uint8_t xpos, uint8_t ypos) {
  I2C_start(OLED_ADDR);                   // start transmission to OLED
  I2C_write(OLED_CMD_MODE);               // set command mode
  I2C_write(xpos & 0x0F);                 // set low nibble of start column
  I2C_write(0x10 | (xpos >> 4));          // set high nibble of start column
  I2C_write(0xB0 | (ypos & 0x07));        // set start page
  I2C_stop();                             // stop transmission
  OLED_x = xpos; OLED_y = ypos;           // set the cursor variables
}

// OLED clear line
void OLED_clearLine(uint8_t line) {
  OLED_setCursor(0, line);                // set cursor to line start
  I2C_start(OLED_ADDR);                   // start transmission to OLED
  I2C_write(OLED_DAT_MODE);               // set data mode
  for(uint8_t i=128; i; i--) I2C_write(0x00); // clear the line
  I2C_stop();                             // stop transmission
}

// OLED clear screen
void OLED_clearScreen(void) {
  for(uint8_t i=0; i<4; i++)              // 4 lines
    OLED_clearLine(i);                    // clear line
}

// OLED print a single character
void OLED_printChar(char c) {
  uint16_t ptr = c - 32;                  // character pointer
  ptr += ptr << 2;                        // -> ptr = (ch - 32) * 5;
  I2C_write(0x00);                        // write space between characters
  for(uint8_t i=5 ; i; i--) I2C_write(pgm_read_byte(&OLED_FONT[ptr++]));
  OLED_x += 6;                            // update cursor
  if(OLED_x > 122) {                      // line end ?
    I2C_stop();                           // stop data transmission
    OLED_setCursor(0,++OLED_y);           // set next line start
    I2C_start(OLED_ADDR);                 // start transmission to OLED
    I2C_write(OLED_DAT_MODE);             // set data mode
  }
}

// OLED print a string from program memory
void OLED_printPrg(const char* p) {
  I2C_start(OLED_ADDR);                   // start transmission to OLED
  I2C_write(OLED_DAT_MODE);               // set data mode
  char ch = pgm_read_byte(p);             // read first character from program memory
  while(ch) {                             // repeat until string terminator
    OLED_printChar(ch);                   // print character on OLED
    ch = pgm_read_byte(++p);              // read next character
  }
  I2C_stop();                             // stop transmission
}

// OLED convert byte nibble into hex character and prints it
void OLED_printNibble(uint8_t nibble) {
  (nibble <= 9) ? (nibble += '0') : (nibble += ('A' - 10));
  OLED_printChar(nibble);
}

// OLED print byte as hex
void OLED_printHex(uint8_t value) {
  I2C_start(OLED_ADDR);                   // start transmission to OLED
  I2C_write(OLED_DAT_MODE);               // set data mode
  OLED_printNibble(value >> 4);           // print high nibble
  OLED_printNibble(value & 0x0F);         // print low nibble
  I2C_stop();                             // stop transmission
}

// OLED BCD conversion array
const uint16_t DIVIDER[] PROGMEM = {10000, 1000, 100, 10, 1};

// OLED print 16-bit value as decimal (BCD conversion by substraction method)
void OLED_printDec(uint16_t value) {
  uint8_t leadflag = 0;
  I2C_start(OLED_ADDR);                         // start transmission to OLED
  I2C_write(OLED_DAT_MODE);                     // set data mode
  for(uint8_t digit = 0; digit < 5; digit++) {  // 5 digits
    uint8_t digitval = 0;                       // start with digit value 0
    uint16_t divider = pgm_read_word(&DIVIDER[digit]);  // current divider
    while(value >= divider) {                   // if current divider fits into the value
      leadflag = 1;                             // end of leading spaces
      digitval++;                               // increase digit value
      value -= divider;                         // decrease value by divider
    }
    if(leadflag || (digit == 4)) OLED_printChar('0' + digitval);   // print the digit
    else OLED_printChar(' ');                   // print leading space
  }
  I2C_stop();                                   // stop transmission
}

// ===================================================================================
// High-Voltage Serial Programmer Implementation
// ===================================================================================

// Target devices definitions
#define TGT_ERROR         0
#define TGT_T13           1
#define TGT_T25           2
#define TGT_T45           3
#define TGT_T85           4

// Desired fuse configuration (defaults) for ATtiny13
#define T13_LFUSE         0x6A
#define T13_HFUSE         0xFF

// Desired fuse configuration (defaults) for ATtiny25/45/85
#define Tx5_LFUSE         0x62
#define Tx5_HFUSE         0xDF
#define Tx5_EFUSE         0xFF

// Signatures
#define T13_SIG           0x9007
#define T25_SIG           0x9108
#define T45_SIG           0x9206
#define T85_SIG           0x930B

// HVSP macros
#define HVSP_RST_12V()    PORTA |=  (1<<HVR_PIN)
#define HVSP RST_HIGH()   PORTA =   (PORTA & (~(1<<HVR_PIN))) | (1<<RST_PIN)
#define HVSP_RST_LOW()    PORTA &= ~((1<<RST_PIN) | (1<<HVR_PIN))
#define HVSP_VCC_ON()     PORTB |=  (1<<VCC_PIN)
#define HVSP_VCC_OFF()    PORTB &= ~(1<<VCC_PIN)
#define HVSP_SCI_HIGH()   PORTA |=  (1<<SCI_PIN)
#define HVSP_SCI_LOW()    PORTA &= ~(1<<SCI_PIN)
#define HVSP_SII_HIGH()   PORTA |=  (1<<SII_PIN)
#define HVSP_SII_LOW()    PORTA &= ~(1<<SII_PIN)
#define HVSP_SDI_HIGH()   PORTA |=  (1<<SDI_PIN)
#define HVSP_SDI_LOW()    PORTA &= ~(1<<SDI_PIN)
#define HVSP_SDO_REL()    DDRA  &= ~(1<<SDO_PIN)
#define HVSP_SDO_BIT      (PINA &   (1<<SDO_PIN))
#define HVSP_CLOCKOUT()   HVSP_SCI_HIGH(); HVSP_SCI_LOW()
#define HVSP_BUSY_WAIT()  while(!HVSP_SDO_BIT)

// Program for ATtiny13
const uint8_t PROG_T13_LENGTH = 72;
const uint8_t PROG_T13[] PROGMEM = {
  0x09, 0xC0, 0x0E, 0xC0, 0x0D, 0xC0, 0x0C, 0xC0, 0x0B, 0xC0, 0x0A, 0xC0, 0x09, 0xC0, 0x08, 0xC0,
  0x07, 0xC0, 0x06, 0xC0, 0x11, 0x24, 0x1F, 0xBE, 0xCF, 0xE9, 0xCD, 0xBF, 0x02, 0xD0, 0x12, 0xC0,
  0xEF, 0xCF, 0x80, 0xE0, 0x90, 0xE0, 0x07, 0xD0, 0x81, 0xBF, 0x81, 0xE0, 0x87, 0xBB, 0x92, 0xE4,
  0x9F, 0xBD, 0x83, 0xBF, 0xFF, 0xCF, 0xE1, 0x99, 0xFE, 0xCF, 0x8E, 0xBB, 0xE0, 0x9A, 0x99, 0x27,
  0x8D, 0xB3, 0x08, 0x95, 0xF8, 0x94, 0xFF, 0xCF
};

// Program for ATtiny25/45/85
const uint8_t PROG_Tx5_LENGTH = 84;
const uint8_t PROG_Tx5[] PROGMEM = {
  0x0E, 0xC0, 0x13, 0xC0, 0x12, 0xC0, 0x11, 0xC0, 0x10, 0xC0, 0x0F, 0xC0, 0x0E, 0xC0, 0x0D, 0xC0,
  0x0C, 0xC0, 0x0B, 0xC0, 0x0A, 0xC0, 0x09, 0xC0, 0x08, 0xC0, 0x07, 0xC0, 0x06, 0xC0, 0x11, 0x24,
  0x1F, 0xBE, 0xCF, 0xED, 0xCD, 0xBF, 0x02, 0xD0, 0x13, 0xC0, 0xEA, 0xCF, 0x80, 0xE0, 0x90, 0xE0,
  0x07, 0xD0, 0x81, 0xBF, 0x81, 0xE0, 0x87, 0xBB, 0x92, 0xE4, 0x9A, 0xBD, 0x83, 0xBF, 0xFF, 0xCF,
  0xE1, 0x99, 0xFE, 0xCF, 0x1F, 0xBA, 0x8E, 0xBB, 0xE0, 0x9A, 0x99, 0x27, 0x8D, 0xB3, 0x08, 0x95,
  0xF8, 0x94, 0xFF, 0xCF
};

// HVSP set up all control lines (output LOW)
void HVSP_init(void) {
  PORTA &= ~((1<<HVR_PIN) | (1<<RST_PIN) | (1<<SCI_PIN) | (1<<SDO_PIN) | (1<<SII_PIN) | (1<<SDI_PIN));
  DDRA  |=   (1<<HVR_PIN) | (1<<RST_PIN) | (1<<SCI_PIN) | (1<<SDO_PIN) | (1<<SII_PIN) | (1<<SDI_PIN);
  PORTB &=  ~(1<<VCC_PIN);
  DDRB  |=   (1<<VCC_PIN);
}

// HVSP release all control lines (input, no pullup)
void HVSP_release(void) {
  PORTA &= ~((1<<HVR_PIN) | (1<<RST_PIN) | (1<<SCI_PIN) | (1<<SDO_PIN) | (1<<SII_PIN) | (1<<SDI_PIN));
  DDRA  &= ~((1<<HVR_PIN) | (1<<RST_PIN) | (1<<SCI_PIN) | (1<<SDO_PIN) | (1<<SII_PIN) | (1<<SDI_PIN));
  PORTB &=  ~(1<<VCC_PIN);
  DDRB  &=  ~(1<<VCC_PIN);
}

// HVSP enter the programming mode
void HVSP_enterProgMode(void) {
  HVSP_init();                        // initialize control lines
  HVSP_VCC_ON();                      // apply VCC to target
  _delay_us(20);                      // wait 20us
  HVSP_RST_12V();                     // apply 12V to RESET pin of target
  _delay_us(10);                      // wait 10us
  HVSP_SDO_REL();                     // release SDO line
  _delay_us(300);                     // delay 300us
}

// HVSP exit the programming mode
void HVSP_exitProgMode(void) {
  HVSP_SCI_LOW();                     // set SCI line LOW
  HVSP_RST_LOW();                     // RESET to 0V
  HVSP_VCC_OFF();                     // power down the target
  HVSP_release();                     // release all control lines
}
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
int main(void) {
  // Setup
  ADC_init();                       // setup ADC
  FRQ_init();                       // setup timers for frequency measurements
  OLED_init();                      // setup I2C OLED

  // Loop
  while(1) {
    // Print title screen
    OLED_clearScreen();
    OLED_setCursor(0,0);
    OLED_printPrg(TitleScreen);
    waitButton();

    // Detect target and read device information
    OLED_clearScreen();
    OLED_setCursor(0,0);
    OLED_printPrg(PSTR("Detecting ..."));
    for(uint8_t i=8; i; i--) {
      HVSP_enterProgMode();
      HVSP_readSignature();
      HVSP_exitProgMode();
      if(target != TGT_ERROR) break;
      _delay_ms(100);
    }

    // Print detected device or ERROR
    OLED_setCursor(0,0);
    OLED_printPrg(PSTR("Detected: "));
    if(target == TGT_ERROR) {
      OLED_printPrg(PSTR("ERROR !"));
      OLED_setCursor(0,1);
      OLED_printPrg(ErrorScreen);
      waitButton();
      continue;
    }

    OLED_printPrg(PSTR("ATtiny"));
    switch(target) {
      case TGT_T13:   OLED_printHex(0x13); break;
      case TGT_T25:   OLED_printHex(0x25); break;
      case TGT_T45:   OLED_printHex(0x45); break;
      case TGT_T85:   OLED_printHex(0x85); break;
      default:        break;
    }

    // Print main menu
    OLED_setCursor(0,1); OLED_printPrg(SelectScreen);

    // Read button and execute selected function
    uint8_t button = waitButton();
    switch(button) {
      case 1:         TGT_calibrate(); break;
      case 2:         TGT_resetFuses(); break;
      default:        break;
    }
  }
}

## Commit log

2020-12-27 Update files
    [TinyCalibrator_BOM.tsv, TinyCalibrator_case.fcstd, TinyCalibrator_case.stl]
2021-06-08 Correct wrong toggle switch in BOM
    [TinyCalibrator_BOM.tsv]
2022-09-09 Update BOM
    [TinyCalibrator_BOM.tsv]
